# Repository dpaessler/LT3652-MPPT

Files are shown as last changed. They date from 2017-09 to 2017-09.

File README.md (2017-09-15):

# LT3652-MPPT
LT3652 based MPPT solar charger for a single LiFePo4 cell 

The LT3652 is a 2A multi chemistry MPPT charger controller from Linear Technology.
You can charge other cells by simply changing the values for R1 - R4 (R1 and R2 actually are _one_ resistor with 223k for LiFePo4) according to the datasheet.
Set the trim potentiometer to 2.8V on pin VIN_REG at full sun on the solar panel.

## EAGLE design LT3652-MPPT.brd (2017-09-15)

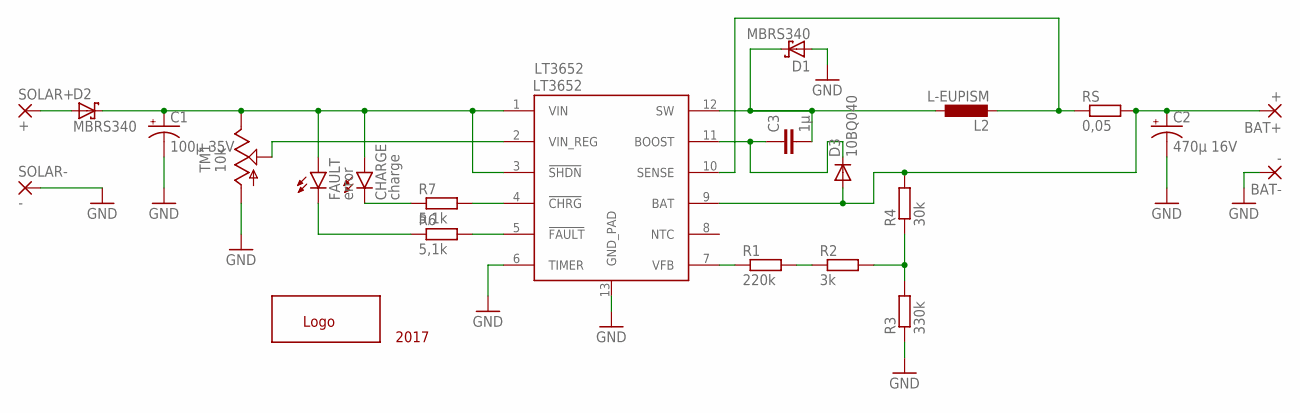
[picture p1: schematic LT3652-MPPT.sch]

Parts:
BAT+: +; 3,81/1,4
BAT-: -; 3,81/1,4
C1: 100µ 35V; PANASONIC_C
C2: 470µ 16V; PANASONIC_C
C3: 1µ; C0805
CHARGE: charge; LED-1206
D1, D2: MBRS340; SMC
D3: 10BQ040; SMA-DIODE
FAULT: error; LED-1206
L2: L-EUPISM; PISM
LT3652: LT3652; MSOP-12_GND
R1: 220k; R0805
R2: 3k; R0805
R3: 330k; R0805
R4: 30k; R0805
R6, R7: 5,1k; R0805
RS: 0,05; R1206
SOLAR+: +; 3,81/1,4
SOLAR-: -; 3,81/1,4
TM1: 10k; 5MMP
U$1: 2017; LOGO

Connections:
223K: R1.2, R2.1
BAT: BAT+.1, C2.+, D3.A, LT3652.9 (BAT), R4.2, RS.2
BOOST: C3.1, D3.C, LT3652.11 (BOOST)
CHRG: LT3652.4 (!CHRG), R7.2
DIV: R2.2, R3.2, R4.1
FAULT: LT3652.5 (!FAULT), R6.2
GND: BAT-.1, C1.-, C2.-, D1.A, LT3652.6 (TIMER), LT3652.13 (GND_PAD), R3.1, SOLAR-.1, TM1.A
LEDBLUE: CHARGE.C, R7.1
LEDRED: FAULT.C, R6.1
unnamed: D2.A, SOLAR+.1
SENSE: L2.2, LT3652.10 (SENSE), RS.1
SW: C3.2, D1.C, L2.1, LT3652.12 (SW)
VFB: LT3652.7 (VFB), R1.1
VIN: C1.+, CHARGE.A, D2.C, FAULT.A, LT3652.1 (VIN), LT3652.3 (!SHDN), TM1.E
VREG: LT3652.2 (VIN_REG), TM1.S

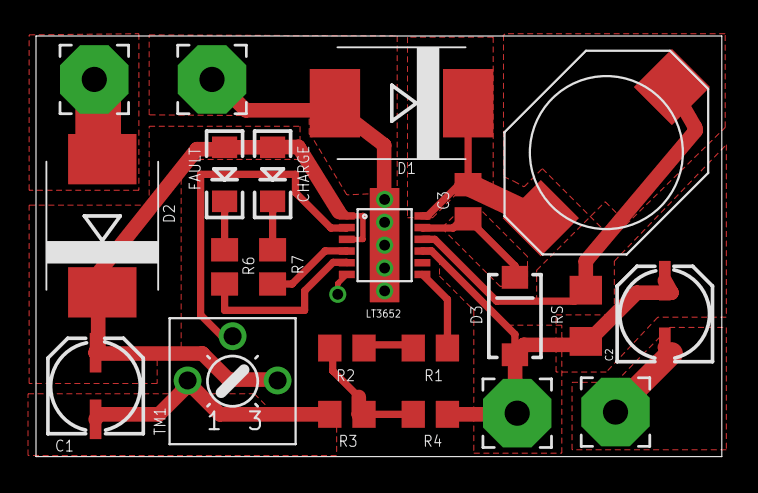
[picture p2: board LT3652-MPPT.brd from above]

Board: 2 copper layers, 38.1 x 23.4 mm, 23 parts (1 on the bottom side), 15 nets.

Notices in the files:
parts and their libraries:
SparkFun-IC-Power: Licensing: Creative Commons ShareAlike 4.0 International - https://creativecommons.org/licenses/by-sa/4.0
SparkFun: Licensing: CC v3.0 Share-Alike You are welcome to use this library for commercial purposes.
